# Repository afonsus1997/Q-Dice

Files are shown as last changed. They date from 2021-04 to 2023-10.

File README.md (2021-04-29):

# Q-Dice 

## Quantum dice rolls!!

Open source quantum powered digital dice.



### Resources

* Tm1638 7-seg display driver
  * [Datasheet](https://pdf1.alldatasheet.com/datasheet-pdf/view/1132372/TITAN/TM1638.html)
  * [Diagram](https://www.handsontec.com/dataspecs/display/TM1638.pdf)
  * [mbed](https://os.mbed.com/components/TM1638-LED-controller-80-LEDs-max-Keyboa/)

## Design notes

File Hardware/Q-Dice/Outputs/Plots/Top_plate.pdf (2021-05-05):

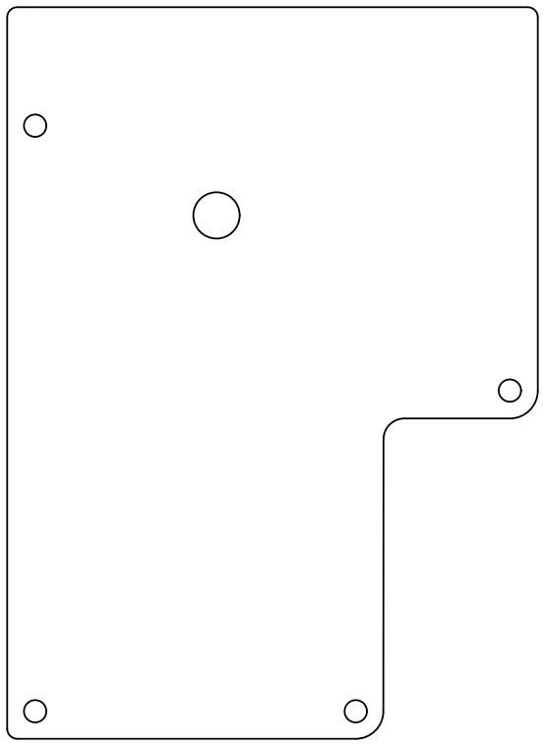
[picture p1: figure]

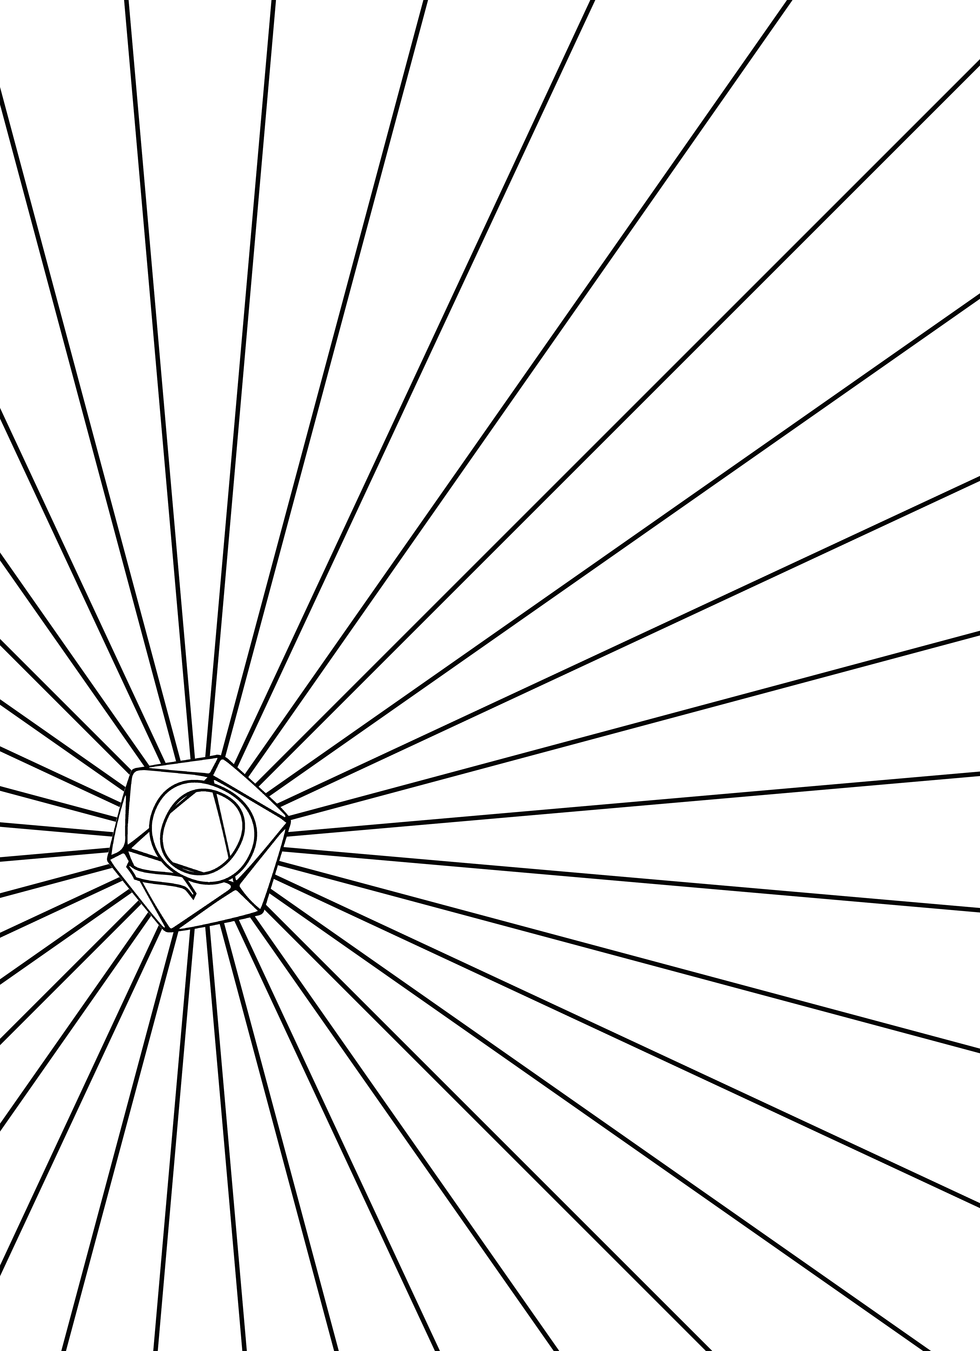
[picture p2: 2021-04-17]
Artwork/back_export.png

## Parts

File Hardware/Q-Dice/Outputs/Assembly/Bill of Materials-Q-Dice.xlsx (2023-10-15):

Designator | Quantity | Comment | Description | Footprint | LibRef
BOOT0 | 1 | 2-Way Solder Jumper |  | SOLDERJUMPER_2WAY_OPEN_NOPASTE | SOLDERJUMPER_2WAY0603
BT1, BT2 | 2 | Holder Cr2032 Gold Leads Smd |  | AAA holder smd | BU2032SM-BT-GTR
CB1, CB2 | 2 | Cap | Capacitor | CAP0603R | Cap
CH1, CH4 | 2 | Cap | Capacitor | C 0603 / 1608 | Cap
CH2, CH3 | 2 | Cap | Capacitor | CAP1206R | Cap
CU2 | 1 | 100nF |  | CAP0603R | Capacitor
DB1 | 1 | SS34 | Default Diode | DO-214AC | Diode
DH1 | 1 | MMSD4148T1G | Switching Diode, 2-Pin SOD-123, Pb-Free, Tape and Reel | ONSC-SOD-123-2-425-04_V | CMP-0895-00001-2
DH2 | 1 | BYG23M | Default Diode | DO-214AC | Diode
DH3 | 1 | LED |  | LED 0603 | LED
DS1 | 1 | 0.36'' |  | 7-seg 3bit 0.36 | BA56-12EWA
DS2 | 1 | 0.56'' |  | BA56-12EWA | BA56-12EWA
JB1, JB2, RB1, RB2, RB3, RB4, RB5, RH1, RH2, RH3, RH4, RH6, RH9, RH10, RH11, RH12, RH13, RH14, RH15, RU1, RU2, RU3, RU4, RU5, RU6, RU7, RU8 | 27 | Res1 | Resistor | RES0603R | Res1
JH1, JH? | 2 | Fuse Clip |  | FUSE_BK-6003 | Fuse Clip
JU1 | 1 | JMP | Resistor | RES0603R | Res1
LB1 | 1 | Inductor | Inductor | INDUCTOR CD54 | Inductor
LH1 | 1 | 12LRS156C | Inductor | IND_12LRS156C | Inductor_Shielded
P1, P2 | 2 | Header 4 | Header, 4-Pin | HDR1X4 | Header 4
P3 | 1 | Header 2 | Header, 2-Pin | HDR1X2 | Header 2
QB1, QH4 | 2 | SSF1341 | P-Channel Power MOSFET PMV65XP | SOT23 | PMOS
QH1 | 1 | STN0214 | NPN Bipolar Transistor | SOT-223-3 - NPN | NPN
QH2, QH3 | 2 | MMBT4401 | General Purpose Transistor, NPN, 0.6 A IC Continuous, 3-Pin SOT23, RoHS, Tape and Reel | ONSC-SOT-23-3-318-08_M | CMP-0722-00001-1
QH5 | 1 | FDN335N | N-Channel Power MOSFET PMV30UN | SOT23 | NMOS
RH5 | 1 | 10R | 3314G-1-502E | 4 mm Square Trimpot(R) Trimming Potentiometer, 5 KOhm, +/- 20%, 0.25 W, -55 to 125 degC, 3-Pin SMD, RoHS, Tape and Reel | BOUR-3314G-1_V | CMP-2000-05589-1
RH7, RH8 | 2 | Res1 | Resistor | RES0805R | Res1
SW1, SW2, SW3 | 3 | EVQ-PAE05R | SWITCH TACTILE SPST-NO 0.02A 15V | FP-EVQ-PAE05R-MFG | CMP-05618-000051-1
SW4 | 1 | FSM100 | SWITCH TACTILE SPST-NO 0.05A 24V | FP-FSM100-MFG | CMP-03402-000014-1
SW5 | 1 | Switch |  | PUSH_SMD_3x4 | B3U-1000P
SW6 | 1 | JS202011SCQN | SWITCH SLIDE DPDT 300MA 6V | JS202011SCQN | JS202011SCQN
TPH1 | 1 | HV_TP |  | TESTPOINT_SMT | TESTPOINT
UB1 | 1 | MT3608 | Boost converter | SOT23-6 | MT3608
UH1 | 1 | NE555P |  | SOIC-8 | NE555P
UU1 | 1 | STM32L053C8T6 | ARMÂ® CortexÂ®-M0+ STM32L0 Microcontroller IC 32-Bit 32MHz 64KB _64K x 8_ FLASH 48-LQFP _7x7_ | LQFP48_7X7MM_0.5MMPP | STM32L053C8T6
UU2 | 1 | TM1638 | 7Seg and keyboard driver | SOP-28 | TM1638

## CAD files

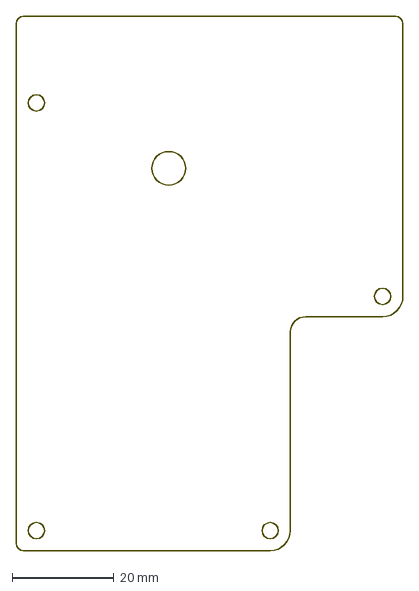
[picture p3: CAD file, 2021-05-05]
Hardware/Q-Dice/Outputs/Plots/Top_plate.DXF
76.0 x 105.0 mm

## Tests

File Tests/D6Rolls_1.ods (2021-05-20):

Dados Históricos
TIME | CH1
20:12:30.17 | 2
20:12:26.92 | 1
20:12:23.32 | 5
20:12:19.59 | 6
20:12:15.48 | 3
20:12:14.38 | 4
20:12:11.02 | 5
20:12:10.89 | 6
20:12:06.22 | 6
20:12:02.99 | 6
20:11:59.48 | 3
20:11:57.77 | 6
20:11:52.44 | 3
20:11:45.64 | 1
20:11:44.19 | 6
20:11:43.87 | 3
20:11:38.67 | 6
20:11:37.69 | 4
20:11:32.68 | 4
20:11:27.77 | 2
20:11:26.56 | 3
20:11:26.06 | 5
20:11:18.01 | 4
20:11:15.53 | 4
20:11:12.72 | 4
20:11:10.36 | 4
20:11:07.93 | 4
20:11:04.40 | 4
20:10:54.44 | 4
20:10:52.16 | 2
20:10:37.60 | 3
20:10:32.62 | 3
20:10:30.83 | 5
20:10:25.04 | 4
20:10:21.13 | 4
20:10:18.06 | 1
20:10:14.40 | 2
20:10:13.16 | 3
20:10:11.71 | 6
20:10:10.48 | 6
20:10:09.77 | 5
20:10:08.70 | 5
20:10:07.18 | 5
20:10:03.79 | 6
20:10:00.17 | 5
20:09:53.13 | 6
20:09:47.84 | 1
20:09:44.59 | 4
20:09:43.48 | 1
20:09:43.24 | 5
20:09:41.52 | 1
20:09:37.60 | 4
20:09:36.84 | 5
20:09:35.47 | 4
20:09:34.03 | 1
20:09:32.96 | 1
20:09:30.52 | 2
20:09:28.56 | 3
20:09:20.28 | 4
20:09:15.12 | 6
20:09:13.90 | 5
20:09:06.78 | 2
20:09:06.08 | 4
20:09:05.79 | 4
20:08:53.60 | 3
20:08:45.52 | 6
20:08:43.31 | 3
20:08:42.56 | 5
20:08:42.22 | 2
20:08:41.39 | 6
20:08:37.82 | 1
20:08:29.98 | 1
20:08:21.90 | 3
20:08:20.24 | 1
20:08:20.03 | 5
20:08:17.72 | 2
20:08:09.20 | 3
20:07:59.18 | 1
20:07:59.15 | 4
20:07:56.27 | 1
20:07:54.97 | 4
20:07:51.13 | 5
20:07:36.30 | 4
20:07:32.67 | 6
20:07:29.82 | 3
20:07:25.63 | 6
20:07:19.77 | 6
20:07:15.55 | 4
20:07:13.95 | 3
20:07:09.04 | 2
20:07:07.64 | 1
20:07:04.86 | 4
20:07:03.23 | 6
20:07:01.36 | 4
20:06:59.61 | 4
20:06:56.04 | 6
20:06:48.28 | 3
20:06:47.53 | 2
20:06:44.36 | 1
20:06:40.96 | 4
20:06:37.31 | 6
20:06:34.43 | 2
20:06:33.53 | 4
20:06:33.39 | 5
20:06:28.71 | 6
20:06:25.48 | 5
20:06:14.27 | 4
20:06:11.60 | 2
20:06:11.56 | 4
20:06:10.48 | 4
20:06:10.46 | 4
20:06:10.06 | 2
20:06:04.59 | 1
20:05:58.17 | 6
20:05:55.76 | 4
20:05:50.25 | 4
20:05:49.72 | 2
20:05:48.57 | 5
20:05:44.54 | 3
20:05:43.93 | 2
20:05:38.19 | 4
20:05:36.22 | 6
20:05:34.65 | 1
20:05:32.75 | 1
20:05:26.06 | 5
20:05:22.92 | 2
20:05:17.45 | 4
20:05:11.58 | 2
20:05:09.47 | 6
20:05:07.74 | 2
20:05:07.63 | 4
20:05:06.01 | 5
20:05:04.44 | 3
20:05:02.00 | 3
20:05:00.11 | 1
20:04:59.34 | 1
20:04:53.77 | 3
20:04:52.36 | 1
20:04:48.11 | 3
20:04:47.45 | 5
20:04:43.13 | 1
20:04:42.43 | 6
20:04:37.90 | 2
20:04:35.00 | 6
20:04:30.70 | 1
20:04:29.18 | 3
20:04:26.59 | 2
20:04:25.45 | 4
20:04:20.67 | 3
20:04:19.60 | 2
20:04:15.36 | 1
20:04:13.58 | 6
20:04:10.28 | 3
20:04:10.17 | 6
20:04:05.53 | 1
20:04:04.92 | 2
20:03:59.95 | 3
20:03:59.37 | 3
20:03:58.97 | 5
20:03:54.60 | 6
20:03:53.16 | 3
20:03:48.08 | 4
20:03:39.23 | 6
20:03:39.04 | 1
20:03:38.48 | 3
20:03:28.51 | 4
20:03:24.32 | 6
20:03:24.30 | 3
20:03:11.72 | 1
20:03:08.76 | 2
20:03:08.36 | 2
20:03:07.34 | 1
20:03:03.68 | 4
20:03:02.59 | 5
20:02:58.46 | 1
20:02:53.77 | 3
20:02:52.80 | 2
20:02:51.48 | 6
20:02:49.98 | 4
20:02:48.16 | 3
20:02:45.13 | 4
20:02:42.03 | 4
20:02:41.60 | 5
20:02:38.80 | 1
20:02:35.04 | 5
20:02:32.97 | 1
20:02:32.12 | 5
20:02:29.40 | 3
20:02:26.14 | 3
20:02:22.99 | 3
20:02:22.54 | 3
20:02:21.80 | 1
20:02:21.07 | 4
20:02:19.85 | 5
20:02:18.65 | 1
20:02:17.87 | 4
20:02:17.58 | 3
20:02:14.14 | 6
20:02:12.03 | 1
20:02:09.40 | 6
20:01:59.88 | 1
20:01:57.53 | 6
20:01:55.32 | 1
20:01:53.55 | 1
20:01:50.84 | 2
20:01:49.21 | 3
20:01:46.72 | 4
20:01:44.67 | 3
20:01:39.61 | 5
20:01:38.75 | 4
20:01:36.16 | 6
20:01:35.24 | 2
20:01:34.65 | 4
20:01:34.52 | 2
20:01:33.45 | 2
20:01:33.08 | 5
20:01:32.73 | 4
20:01:30.51 | 4
20:01:26.54 | 3
20:01:25.63 | 2
20:01:24.32 | 6
20:01:22.44 | 6
20:01:21.98 | 5
20:01:20.75 | 3
20:01:19.53 | 4
20:01:15.84 | 6
20:01:15.18 | 2
20:01:11.32 | 5
20:01:06.67 | 3
20:01:04.64 | 2
20:01:02.28 | 1
20:01:01.28 | 1
20:01:00.28 | 3
20:00:58.67 | 2
20:00:55.12 | 6
20:00:52.65 | 2
20:00:51.69 | 5
20:00:50.11 | 6
20:00:47.98 | 5
20:00:44.46 | 1
20:00:41.31 | 3
20:00:37.34 | 2
20:00:33.98 | 5
20:00:26.43 | 4
20:00:22.49 | 1
20:00:20.40 | 3
20:00:16.46 | 3
20:00:15.47 | 4
20:00:11.98 | 4
20:00:09.00 | 1
20:00:08.65 | 3
20:00:04.88 | 2
20:00:02.96 | 1
20:00:02.46 | 3
19:59:59.58 | 2
19:59:57.13 | 5
19:59:55.29 | 3
19:59:51.95 | 1
19:59:48.92 | 3
19:59:44.27 | 4
19:59:42.86 | 5
19:59:38.62 | 1
19:59:35.92 | 1
19:59:34.41 | 1
19:59:32.55 | 6
19:59:32.52 | 4
19:59:28.28 | 3
19:59:25.88 | 3
19:59:23.56 | 1
19:59:20.97 | 2
19:59:16.14 | 4
19:59:12.03 | 4
19:59:08.06 | 3
19:59:02.73 | 5
19:59:01.80 | 4
19:59:01.69 | 5
19:58:58.27 | 4
19:58:54.99 | 2
19:58:52.88 | 1
19:58:49.13 | 1
19:58:44.62 | 5
19:58:42.65 | 3
19:58:36.81 | 6
19:58:29.52 | 2
19:58:21.87 | 5
19:58:16.91 | 5
19:58:14.72 | 2
19:58:13.55 | 1
19:58:06.24 | 3
19:58:01.08 | 5
19:57:59.40 | 3
19:57:56.81 | 2
19:57:54.44 | 1
19:57:50.33 | 5
19:57:48.76 | 4
19:57:48.30 | 1
19:57:40.20 | 1
19:57:40.03 | 3
19:57:35.74 | 3
19:57:33.74 | 6
19:57:32.63 | 1
19:57:29.37 | 6
19:57:26.51 | 6
19:57:24.99 | 6
19:57:21.68 | 2
19:57:15.98 | 3
19:57:14.80 | 3
19:57:14.38 | 2
19:57:12.59 | 4
19:57:05.72 | 6
19:57:05.60 | 1
19:57:04.51 | 2
19:57:00.83 | 3
19:56:58.41 | 4
19:56:56.03 | 4
19:56:54.52 | 2
19:56:54.32 | 5
19:56:49.40 | 3
19:56:46.14 | 1
19:56:44.03 | 6
19:56:39.90 | 5
19:56:37.92 | 4
19:56:34.76 | 2
19:56:29.76 | 3
19:56:25.61 | 2
19:56:23.53 | 6
19:56:20.46 | 1
19:56:15.19 | 2
19:56:08.48 | 1
19:56:05.61 | 1
19:56:04.46 | 3
19:55:57.76 | 4
19:55:53.52 | 3
19:55:52.35 | 5
19:55:47.15 | 4
19:55:41.34 | 5
19:55:40.78 | 1
19:55:36.99 | 1
19:55:35.58 | 6
19:55:24.11 | 2
19:55:21.18 | 3
19:55:08.27 | 4
19:55:03.90 | 4
19:55:00.14 | 5
19:54:53.10 | 5
19:54:49.61 | 4
19:54:47.69 | 5
19:54:44.64 | 5
19:54:41.29 | 6
19:54:41.00 | 1
19:54:38.91 | 3
19:54:35.74 | 5
19:54:31.40 | 4
19:54:28.09 | 2
19:54:25.50 | 3
19:54:24.48 | 3
19:54:20.89 | 5
19:54:18.70 | 6
19:54:17.48 | 5
19:54:09.56 | 4
19:54:09.36 | 3
19:54:08.83 | 5
19:54:05.61 | 2
19:54:02.46 | 2
19:54:00.17 | 3
19:53:59.76 | 5
19:53:59.61 | 3
19:53:59.12 | 1
19:53:58.83 | 3
19:53:52.41 | 2
19:53:51.80 | 6
19:53:50.78 | 3
19:53:47.04 | 5
19:53:43.59 | 3
19:53:43.52 | 6
19:53:35.88 | 1
19:53:34.57 | 6
19:53:33.08 | 1
19:53:32.89 | 4
19:53:28.44 | 1
19:53:26.00 | 2
19:53:18.94 | 4
19:53:16.40 | 6
19:53:09.56 | 6
19:53:08.72 | 6
19:53:06.65 | 1
19:52:59.13 | 6
19:52:58.28 | 4
19:52:54.68 | 3
19:52:51.26 | 2
19:52:44.19 | 1
19:52:40.89 | 5
19:52:36.28 | 3
19:52:32.19 | 3
19:52:30.28 | 1
19:52:29.39 | 1
19:52:26.99 | 2
19:52:24.60 | 1
19:52:21.79 | 3
19:52:19.10 | 2
19:52:17.48 | 2
19:52:13.15 | 3
19:52:11.69 | 2
19:52:11.55 | 1
19:52:09.79 | 4
19:52:09.77 | 6
19:52:06.22 | 6
19:51:57.23 | 6
19:51:55.18 | 6
19:51:49.53 | 5
19:51:47.63 | 6
19:51:46.86 | 3
19:51:45.55 | 1
19:51:45.50 | 1
19:51:43.34 | 5
19:51:41.05 | 1
19:51:36.94 | 1
19:51:36.48 | 2
19:51:35.00 | 1
19:51:28.68 | 6
19:51:25.10 | 4
19:51:22.67 | 2
19:51:19.79 | 3
19:51:06.65 | 1
19:51:04.68 | 2
19:51:02.33 | 3
19:51:00.84 | 6
19:50:56.86 | 3
19:50:56.67 | 2
19:50:53.13 | 2
19:50:48.62 | 6
19:50:47.50 | 4
19:50:42.75 | 1
19:50:42.44 | 1
19:50:34.22 | 3
19:50:32.28 | 4
19:50:31.28 | 4
19:50:27.77 | 3
19:50:25.43 | 1
19:50:20.67 | 5
19:50:17.87 | 1
19:50:14.88 | 6
19:50:12.99 | 3
19:50:09.80 | 6
19:50:05.58 | 3
19:50:03.66 | 6
19:50:01.92 | 3
19:49:58.75 | 6
19:49:55.64 | 3
19:49:50.54 | 6
19:49:46.75 | 2
19:49:46.33 | 5
19:49:46.08 | 6
19:49:44.24 | 2
19:49:38.43 | 3
19:49:37.16 | 4
19:49:35.66 | 6
19:49:34.30 | 6
19:49:28.01 | 6
19:49:23.39 | 4
19:49:19.48 | 1
19:49:16.91 | 1
19:49:16.89 | 1
19:49:16.44 | 1
19:49:14.06 | 2
19:49:13.88 | 3
19:49:09.40 | 5
19:49:07.98 | 5
19:49:01.61 | 4
19:49:00.57 | 2
19:48:57.96 | 3
19:48:55.28 | 3
19:48:54.51 | 6
19:48:52.73 | 3
19:48:48.72 | 2
19:48:46.73 | 1
19:48:43.66 | 5
19:48:42.25 | 2
19:48:37.24 | 3
19:48:35.95 | 3
19:48:35.66 | 1
19:48:34.20 | 5
19:48:29.55 | 6
19:48:26.73 | 5
19:48:19.29 | 3
19:48:15.10 | 4
19:48:14.36 | 3
19:48:11.28 | 2
19:48:10.00 | 3
19:48:04.84 | 2
19:48:03.24 | 1
19:47:58.20 | 2
19:47:54.33 | 5
19:47:46.73 | 2
19:47:42.96 | 6
19:47:38.39 | 1
19:47:36.84 | 6
19:47:35.74 | 3
19:47:34.16 | 6
19:47:31.84 | 4
19:47:17.66 | 6
19:47:07.95 | 4
19:47:06.14 | 4
19:46:57.53 | 1
19:46:56.88 | 2
19:46:49.42 | 1
19:46:47.24 | 3
19:46:45.66 | 6
19:46:37.52 | 2
19:46:22.36 | 4
19:46:20.12 | 4
19:46:08.64 | 5
19:46:05.80 | 6
19:46:02.88 | 1
19:45:57.07 | 2
19:45:56.20 | 6
19:45:55.68 | 3
19:45:53.52 | 6
19:45:48.49 | 3
19:45:42.40 | 1
19:45:38.11 | 4
19:45:34.43 | 6
19:45:31.53 | 5
19:45:26.51 | 3
19:45:19.77 | 6
19:45:17.27 | 3
19:45:17.12 | 2
19:45:15.23 | 1
19:45:14.48 | 2
19:45:10.88 | 6
19:45:07.32 | 3
19:45:04.83 | 3
19:45:02.89 | 1
19:45:01.05 | 5
19:44:58.30 | 1
19:44:56.44 | 4
19:44:55.23 | 3
19:44:52.00 | 3
19:44:50.78 | 6
19:44:43.95 | 4
19:44:41.92 | 5
19:44:38.71 | 4
19:44:37.59 | 4
19:44:37.18 | 5
19:44:30.76 | 4
19:44:30.27 | 1
19:44:28.56 | 1
19:44:26.40 | 1
19:44:24.17 | 1
19:44:21.80 | 4
19:44:13.42 | 2
19:44:09.04 | 6
19:44:08.24 | 5
19:44:05.13 | 5
19:44:00.38 | 4
19:43:58.88 | 6
19:43:53.40 | 3
19:43:52.65 | 6
19:43:45.88 | 4
19:43:45.15 | 5
19:43:39.50 | 6
19:43:36.80 | 6
19:43:33.79 | 1
19:43:27.72 | 6
19:43:25.92 | 3
19:43:22.17 | 3
19:43:21.69 | 1
19:43:21.44 | 3
19:43:19.68 | 4
19:43:18.33 | 1
19:43:13.26 | 2
19:43:11.53 | 5
19:43:04.48 | 5
19:43:03.58 | 5
19:43:01.69 | 3
19:42:59.95 | 3
19:42:59.52 | 4
19:42:52.48 | 5
19:42:50.03 | 3
19:42:48.60 | 4
19:42:46.75 | 4
19:42:46.12 | 6
19:42:43.07 | 6
19:42:42.36 | 1
19:42:39.08 | 3
19:42:38.68 | 1
19:42:31.68 | 5
19:42:27.18 | 1
19:42:26.46 | 1
19:42:25.05 | 5
19:42:23.37 | 4
19:42:17.98 | 4
19:42:15.34 | 4
19:42:14.11 | 1
19:42:13.69 | 3
19:42:05.15 | 3
19:42:02.30 | 1
19:41:57.02 | 1
19:41:55.36 | 4
19:41:51.72 | 3
19:41:49.88 | 2
19:41:37.68 | 4
19:41:37.34 | 5
19:41:35.71 | 5
19:41:29.31 | 2
19:41:26.99 | 1
19:41:23.63 | 2
19:41:20.70 | 6
19:41:19.28 | 3
19:41:09.31 | 5
19:40:57.71 | 1
19:40:53.74 | 3
19:40:50.91 | 2
19:40:47.08 | 6
19:40:44.56 | 1
19:40:41.52 | 2
19:40:37.24 | 3
19:40:33.26 | 4
19:40:32.30 | 1
19:40:29.08 | 4
19:40:25.61 | 6
19:40:21.44 | 1
19:40:16.60 | 4
19:40:10.27 | 1
19:40:07.28 | 3
19:40:05.95 | 3
19:40:04.86 | 2
19:40:04.27 | 3
19:40:03.77 | 5
19:40:01.72 | 4
19:39:59.60 | 6
19:39:55.05 | 4
19:39:49.74 | 1
19:39:37.77 | 1
19:39:37.52 | 3
19:39:31.84 | 1
19:39:28.84 | 3
19:39:27.93 | 3
19:39:25.61 | 1
19:39:25.00 | 6
19:39:21.19 | 6
19:39:18.25 | 3
19:39:14.49 | 2
19:39:14.25 | 6
19:39:08.59 | 5
19:39:07.34 | 3
19:39:05.18 | 4
19:38:59.34 | 3
19:38:58.41 | 4
19:38:52.78 | 4
19:38:47.83 | 6
19:38:45.93 | 1
19:38:45.02 | 6
19:38:42.08 | 6
19:38:42.00 | 5
19:38:36.33 | 4
19:38:33.55 | 2
19:38:28.86 | 5
19:38:28.60 | 4
19:38:26.41 | 5
19:38:23.63 | 6
19:38:22.60 | 1
19:38:20.19 | 3
19:38:19.12 | 5
19:38:16.24 | 1
19:38:13.29 | 2
19:38:12.78 | 4
19:38:08.97 | 1
19:38:05.87 | 2
19:38:04.51 | 4
19:37:58.59 | 5
19:37:56.89 | 3
19:37:51.47 | 2
19:37:48.49 | 3
19:37:42.46 | 4
19:37:42.12 | 4
19:37:39.23 | 1
19:37:35.05 | 1
19:37:33.16 | 5
19:37:20.36 | 3
19:37:16.51 | 2
19:37:13.32 | 3
19:37:10.24 | 2
19:37:07.12 | 6
19:37:04.16 | 3
19:36:59.18 | 1
19:36:53.43 | 6
19:36:49.31 | 4
19:36:45.58 | 4
19:36:42.17 | 5
19:36:41.53 | 2
19:36:39.10 | 6
19:36:37.55 | 1
19:36:37.47 | 2
19:36:36.51 | 3
19:36:36.03 | 1
19:36:28.44 | 1
19:36:24.83 | 1
19:36:23.29 | 1
19:36:17.18 | 2
19:36:16.22 | 1
19:36:05.34 | 4
19:36:02.36 | 1
19:36:00.33 | 1
19:35:47.66 | 2
19:35:46.78 | 4
19:35:45.32 | 2
19:35:39.18 | 5
19:35:32.35 | 4
19:35:32.28 | 5
19:35:23.03 | 6
19:35:21.56 | 4
19:35:17.32 | 6
19:35:05.66 | 1
19:35:04.76 | 3
19:35:03.58 | 4
19:35:03.26 | 1
19:35:02.76 | 5
19:34:58.91 | 3
19:34:55.85 | 2
19:34:51.66 | 4
19:34:50.23 | 4
19:34:43.88 | 2
19:34:42.08 | 3
19:34:37.60 | 3
19:34:34.48 | 1
19:34:29.72 | 1
19:34:24.99 | 1
19:34:24.81 | 2
19:34:20.38 | 4
19:34:16.11 | 3
19:34:14.48 | 2
19:34:09.48 | 5
19:34:07.26 | 3
19:34:05.87 | 6
19:34:01.95 | 3
19:34:00.12 | 1
19:33:56.08 | 3
19:33:50.86 | 3
19:33:44.54 | 6
19:33:43.45 | 5
19:33:38.73 | 1
19:33:36.24 | 6
19:33:29.92 | 5
19:33:20.97 | 3
19:33:18.70 | 3
19:33:14.09 | 2
19:33:12.03 | 1
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

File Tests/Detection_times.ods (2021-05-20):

TIME | CH1
17:47:18.66 | 1
17:47:05.98 | 1
17:47:03.02 | 1
17:46:53.39 | 1
17:46:43.18 | 1
17:46:41.60 | 1
17:46:39.92 | 1
17:46:34.48 | 1
17:46:29.64 | 1
17:46:25.13 | 1
17:46:13.58 | 1
17:45:54.54 | 1
17:45:47.88 | 1
17:45:18.16 | 1
17:45:12.52 | 1
17:45:06.30 | 1
17:45:01.07 | 1
17:44:51.56 | 1
17:44:42.57 | 1
17:44:36.46 | 1
17:44:13.87 | 1
17:44:09.11 | 1
17:44:08.22 | 1
17:43:58.97 | 1
17:43:51.56 | 1
17:43:41.66 | 1
17:43:07.91 | 1
17:42:51.45 | 1
17:42:47.72 | 1
17:42:43.52 | 1
17:42:38.67 | 1
17:42:23.37 | 1
17:42:18.41 | 1
17:42:12.67 | 1
17:42:04.20 | 1
17:41:39.07 | 1
17:41:36.76 | 1
17:41:27.90 | 1
17:41:24.27 | 1
17:41:02.79 | 1
17:40:37.15 | 1
17:40:27.00 | 1
17:40:21.19 | 1
17:40:14.30 | 1
17:40:05.58 | 1
17:40:02.51 | 1
17:39:54.99 | 1
17:39:52.22 | 1
17:39:43.43 | 1
17:39:41.79 | 1
17:39:38.87 | 1
17:39:27.58 | 1
17:39:13.80 | 1
17:39:07.93 | 1
17:39:07.21 | 1
17:39:05.47 | 1
17:39:00.23 | 1
17:38:54.63 | 1
17:38:15.72 | 1
17:38:08.35 | 1
17:38:04.70 | 1
17:37:59.69 | 1
17:37:53.59 | 1
17:37:49.40 | 1
17:37:31.98 | 1
17:37:19.35 | 1
17:37:15.26 | 1
17:37:13.45 | 1
17:37:10.92 | 1
17:37:09.11 | 1
17:37:05.07 | 1
17:37:04.97 | 1
17:36:56.01 | 1
17:36:52.89 | 1
17:36:45.90 | 1
17:36:41.87 | 1
17:36:37.37 | 1
17:36:21.95 | 1
17:36:04.95 | 1
17:36:04.59 | 1
17:35:54.17 | 1
17:35:52.43 | 1
17:35:49.02 | 1
17:35:24.43 | 1
17:35:22.30 | 1
17:35:19.05 | 1
17:35:15.75 | 1
17:35:10.25 | 1
17:34:57.67 | 1
17:34:53.02 | 1
17:34:43.32 | 1
17:34:40.25 | 1
17:34:31.39 | 1
17:34:24.57 | 1
17:34:23.31 | 1
17:34:18.03 | 1
17:34:16.39 | 1
17:34:12.11 | 1
17:34:07.45 | 1
17:34:07.16 | 1
17:33:55.87 | 1
17:33:52.57 | 1
17:33:45.34 | 1
17:33:44.25 | 1
17:33:41.05 | 1
17:33:37.90 | 1
17:33:31.69 | 1
17:33:17.51 | 1
17:33:12.17 | 1
17:33:11.21 | 1
17:33:02.39 | 1
17:32:56.20 | 1
17:32:54.62 | 1
17:32:46.71 | 1
17:32:43.39 | 1
17:32:35.69 | 1
17:32:25.27 | 1
17:32:18.34 | 1
17:32:10.06 | 1
17:32:08.86 | 1
17:31:55.24 | 1
17:31:51.98 | 1
17:31:48.04 | 1
17:31:46.44 | 1
17:31:45.80 | 1
17:31:42.06 | 1
17:31:40.39 | 1
17:31:35.51 | 1
17:31:31.40 | 1
17:31:28.83 | 1
17:31:21.69 | 1
17:31:14.17 | 1
17:31:10.97 | 1
17:31:07.22 | 1
17:31:04.61 | 1
17:31:03.64 | 1
17:30:59.48 | 1
17:30:58.20 | 1
17:30:47.99 | 1
17:30:46.31 | 1
17:30:46.12 | 1
17:30:39.89 | 1
17:30:35.14 | 1
17:30:33.76 | 1
17:30:18.81 | 1
17:30:09.64 | 1
17:30:08.65 | 1
17:30:05.03 | 1
17:30:00.89 | 1
17:29:59.64 | 1
17:29:56.12 | 1
17:29:36.39 | 1
17:29:31.77 | 1
17:29:29.00 | 1
17:29:22.49 | 1
17:29:18.21 | 1
17:29:15.05 | 1
17:29:13.00 | 1
17:29:11.35 | 1
17:29:04.79 | 1
17:28:55.88 | 1
17:28:55.41 | 1
17:28:48.44 | 1
17:28:44.66 | 1
17:28:13.24 | 1
17:28:08.05 | 1
17:28:02.39 | 1
17:27:55.25 | 1
17:27:47.38 | 1
17:27:47.06 | 1
17:27:38.42 | 1
17:27:30.74 | 1
17:27:23.17 | 1
17:27:21.73 | 1
17:27:02.55 | 1
17:27:00.00 | 1
17:26:55.94 | 1
17:26:53.30 | 1
17:26:48.37 | 1
17:26:38.57 | 1
17:26:36.31 | 1
17:26:26.55 | 1
17:26:23.88 | 1
17:26:14.90 | 1
17:26:09.64 | 1
17:26:07.56 | 1
17:26:03.97 | 1
17:26:03.24 | 1
17:26:01.22 | 1
17:25:48.05 | 1
17:25:44.34 | 1
17:25:37.49 | 1
17:25:30.41 | 1
17:25:25.17 | 1
17:25:24.15 | 1
17:25:19.83 | 1
17:25:18.63 | 1
17:25:18.16 | 1
17:25:15.81 | 1
17:25:09.73 | 1
17:25:02.02 | 1
17:24:56.42 | 1
17:24:54.44 | 1
17:24:43.80 | 1
17:24:34.04 | 1
17:24:30.80 | 1
17:24:25.04 | 1
17:24:22.41 | 1
17:24:18.20 | 1
17:24:03.54 | 1
17:24:03.17 | 1
17:24:00.53 | 1
17:23:49.19 | 1
17:23:46.18 | 1
17:23:38.88 | 1
17:23:34.37 | 1
17:23:22.95 | 1
17:23:06.12 | 1
17:23:03.80 | 1
17:22:59.60 | 1
17:22:58.74 | 1
17:22:53.43 | 1
17:22:51.94 | 1
17:22:51.83 | 1
17:22:42.90 | 1
17:22:36.74 | 1
17:22:29.32 | 1
17:22:28.09 | 1
17:22:19.94 | 1
17:22:18.44 | 1
17:21:39.46 | 1
17:21:36.63 | 1
17:21:24.98 | 1
17:21:22.76 | 1
17:21:20.96 | 1
17:21:18.55 | 1
17:21:17.62 | 1
17:21:15.57 | 1
17:21:13.92 | 1
17:21:04.31 | 1
17:21:01.17 | 1
17:21:00.40 | 1
17:20:58.21 | 1
17:20:57.60 | 1
17:20:56.48 | 1
17:20:55.09 | 1
17:20:51.52 | 1
17:20:49.96 | 1
17:20:49.19 | 1
17:20:47.60 | 1
17:20:43.00 | 1
17:20:42.68 | 1
17:20:41.92 | 1
17:20:41.83 | 1
17:20:40.48 | 1
17:20:39.91 | 1
17:20:39.59 | 1
17:20:36.40 | 1
17:20:36.34 | 1
17:20:35.65 | 1
17:20:34.52 | 1
17:20:32.77 | 1
17:20:31.49 | 1
17:20:24.98 | 1
17:20:23.92 | 1
17:20:22.92 | 1
17:20:20.90 | 1
17:20:18.66 | 1
17:20:17.56 | 1
17:20:16.32 | 1
17:20:15.70 | 1
17:20:14.16 | 1
17:20:12.12 | 1
17:20:12.08 | 1
17:20:06.20 | 1
17:20:05.64 | 1
17:20:04.88 | 1
17:20:03.92 | 1
17:20:01.40 | 1
17:19:58.82 | 1
17:19:57.99 | 1
17:19:56.12 | 1
17:19:55.73 | 1
17:19:54.91 | 1
17:19:53.83 | 1
17:19:51.56 | 1
17:19:49.30 | 1
17:19:48.82 | 1
17:19:47.68 | 1
17:19:47.01 | 1
17:19:44.68 | 1
17:19:42.77 | 1
17:19:42.07 | 1
17:19:40.10 | 1
17:19:37.99 | 1
17:19:37.17 | 1
17:19:36.04 | 1
17:19:33.65 | 1
17:19:32.72 | 1
17:19:30.07 | 1
17:19:28.61 | 1
17:19:27.97 | 1
17:19:25.62 | 1
17:19:24.52 | 1
17:19:17.11 | 1
17:19:15.44 | 1
17:19:13.83 | 1
17:19:13.62 | 1
17:19:11.33 | 1
17:19:08.53 | 1
17:19:06.40 | 1
17:19:05.67 | 1
17:19:04.93 | 1
17:19:04.50 | 1
17:18:58.88 | 1
17:18:58.69 | 1
17:18:56.85 | 1
17:18:56.71 | 1
17:18:53.72 | 1
17:18:53.59 | 1
17:18:52.26 | 1
17:18:51.99 | 1
17:18:49.36 | 1
17:18:48.44 | 1
17:18:47.75 | 1
17:18:46.60 | 1
17:18:45.72 | 1
17:18:44.40 | 1
17:18:43.06 | 1
17:18:40.60 | 1
17:18:39.57 | 1
17:18:39.12 | 1
17:18:39.06 | 1
17:18:33.94 | 1
17:18:32.34 | 1
17:18:32.00 | 1
17:18:27.03 | 1
17:18:26.56 | 1
17:18:25.83 | 1
17:18:24.69 | 1
17:18:23.03 | 1
17:18:20.76 | 1
17:18:20.50 | 1
17:18:19.49 | 1
17:18:17.49 | 1
17:18:16.74 | 1
17:18:15.78 | 1
17:18:14.20 | 1
17:18:14.13 | 1
17:18:12.82 | 1
17:18:12.45 | 1
17:18:11.22 | 1
17:18:09.43 | 1
17:18:09.27 | 1
17:18:07.00 | 1
17:18:05.32 | 1
17:18:04.55 | 1
17:18:04.00 | 1
17:18:01.48 | 1
17:18:01.04 | 1
17:17:59.84 | 1
17:17:59.04 | 1
17:17:57.65 | 1
17:17:56.53 | 1
17:17:53.88 | 1
17:17:53.25 | 1
17:17:51.71 | 1
17:17:51.49 | 1
17:17:50.13 | 1
17:17:50.08 | 1
17:17:49.00 | 1
17:17:47.92 | 1
17:17:46.53 | 1
17:17:45.17 | 1
17:17:43.12 | 1
17:17:41.40 | 1
17:17:37.04 | 1
17:17:36.08 | 1
17:17:35.88 | 1
17:17:34.31 | 1
17:17:30.40 | 1
17:17:28.24 | 1
17:17:24.87 | 1
17:17:24.21 | 1
17:17:23.51 | 1
17:17:22.13 | 1
17:17:21.22 | 1
17:17:15.83 | 1
17:17:15.73 | 1
17:17:07.76 | 1
17:17:07.44 | 1
17:17:07.24 | 1
17:17:07.14 | 1
17:17:06.61 | 1
17:17:03.64 | 1
17:17:02.96 | 1
17:17:00.18 | 1
17:16:58.90 | 1
17:16:58.61 | 1
17:16:57.43 | 1
17:16:54.55 | 1
17:16:52.32 | 1
17:16:51.09 | 1
17:16:48.92 | 1
17:16:47.80 | 1
17:16:46.96 | 1
17:16:43.54 | 1
17:16:42.79 | 1
17:16:42.23 | 1
17:16:40.24 | 1
17:16:38.20 | 1
17:16:37.78 | 1
17:16:36.23 | 1
17:16:34.10 | 1
17:16:32.24 | 1
17:16:31.78 | 1
17:16:27.72 | 1
17:16:26.90 | 1
17:16:15.03 | 1
17:16:11.06 | 1
17:16:10.72 | 1
17:16:02.82 | 1
17:16:00.98 | 1
17:15:56.50 | 1
17:15:53.62 | 1
17:15:48.42 | 1
17:15:45.47 | 1
17:15:37.81 | 1
17:15:34.19 | 1
17:15:33.76 | 1
17:15:29.76 | 1
17:15:28.56 | 1

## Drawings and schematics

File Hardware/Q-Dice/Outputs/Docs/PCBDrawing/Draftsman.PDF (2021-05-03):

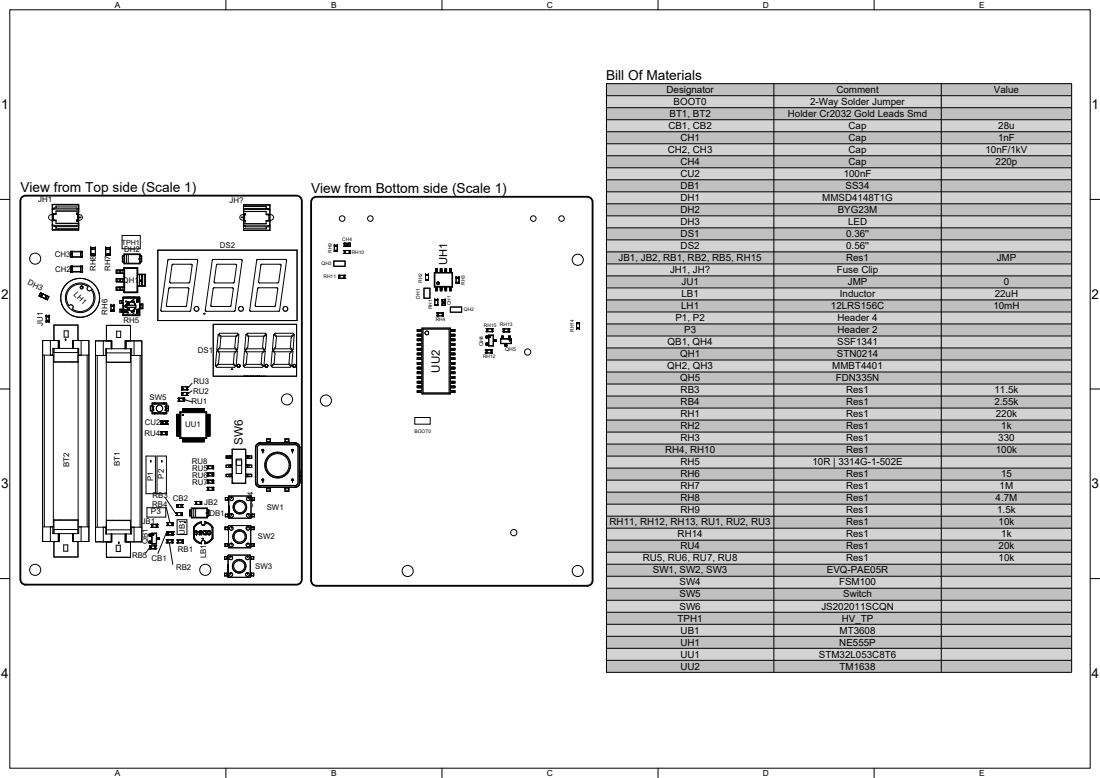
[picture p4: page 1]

Comment
2-Way Solder Jumper
Holder Cr2032 Gold Leads Smd

View from Top side (Scale 1)

View from Bottom side (Scale 1)

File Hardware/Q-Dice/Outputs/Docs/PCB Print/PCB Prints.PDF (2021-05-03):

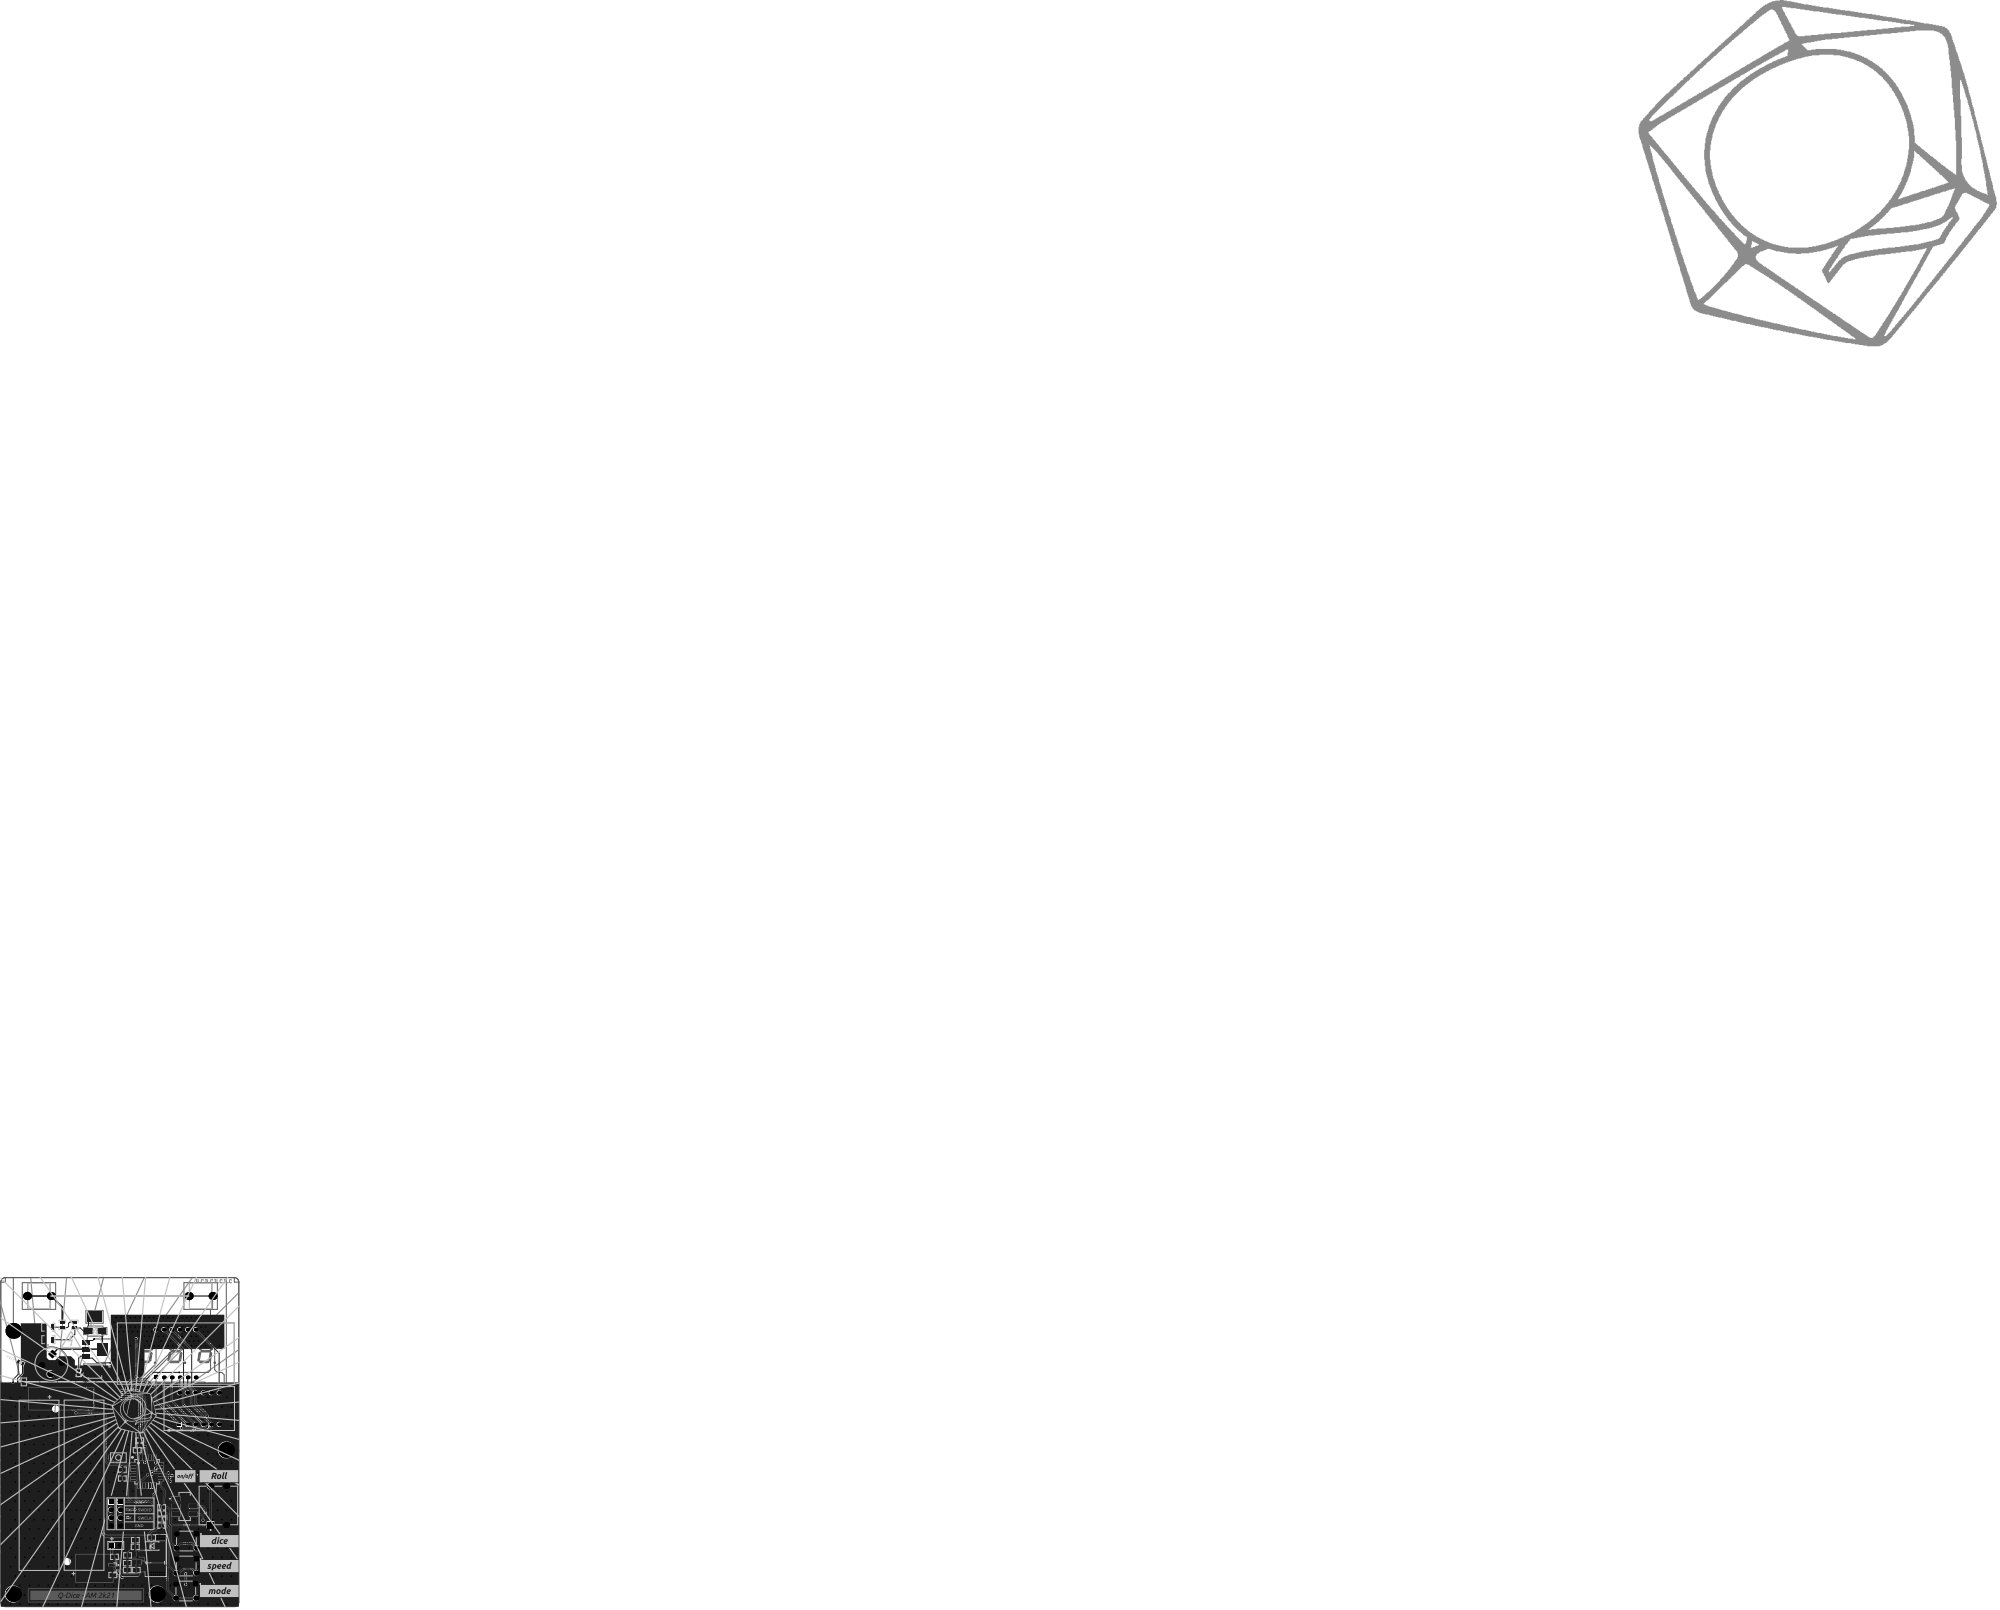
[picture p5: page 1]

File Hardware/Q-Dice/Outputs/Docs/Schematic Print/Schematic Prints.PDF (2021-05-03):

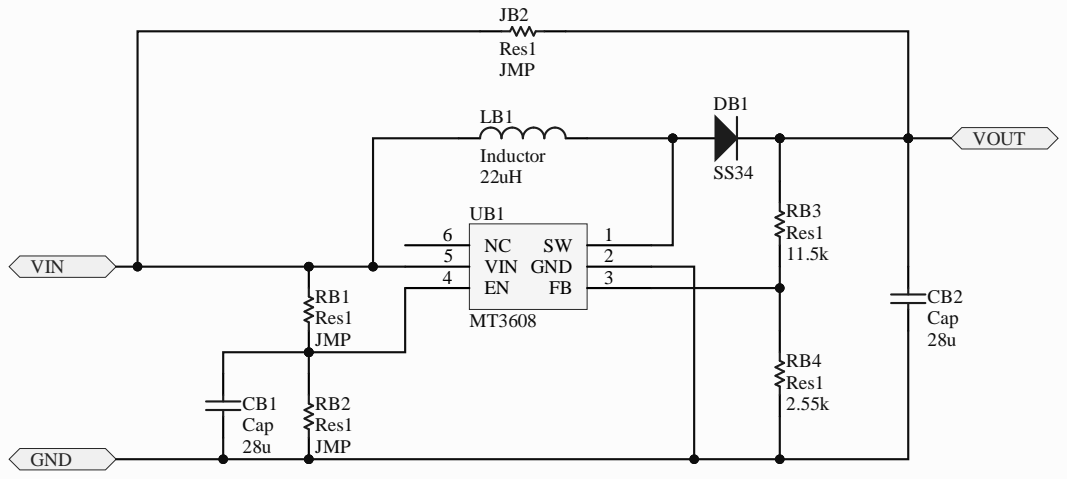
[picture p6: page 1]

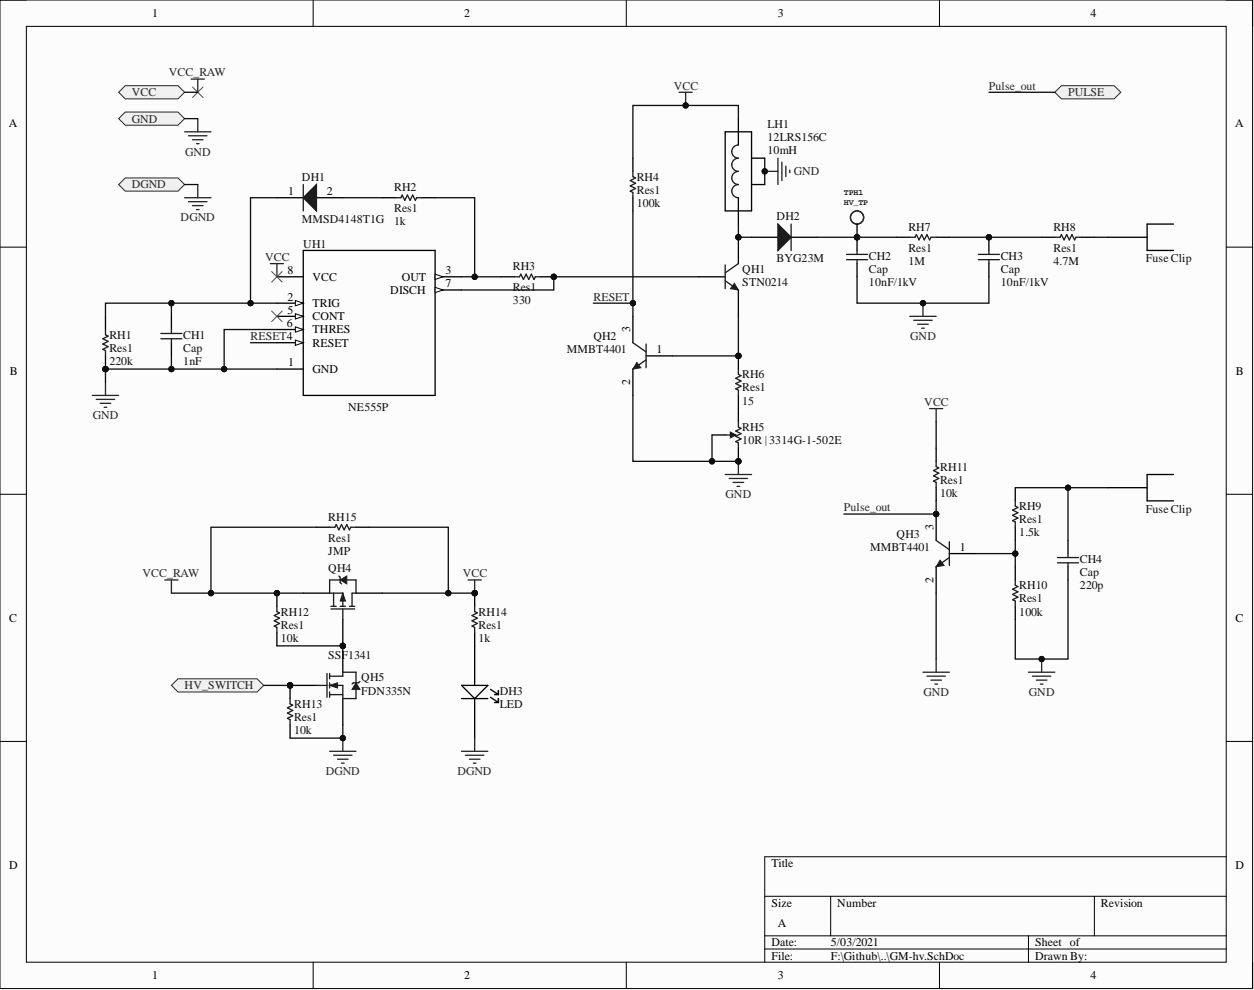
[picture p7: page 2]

RESET 4 THRES 6 CONT 5 TRIG 2

RESET

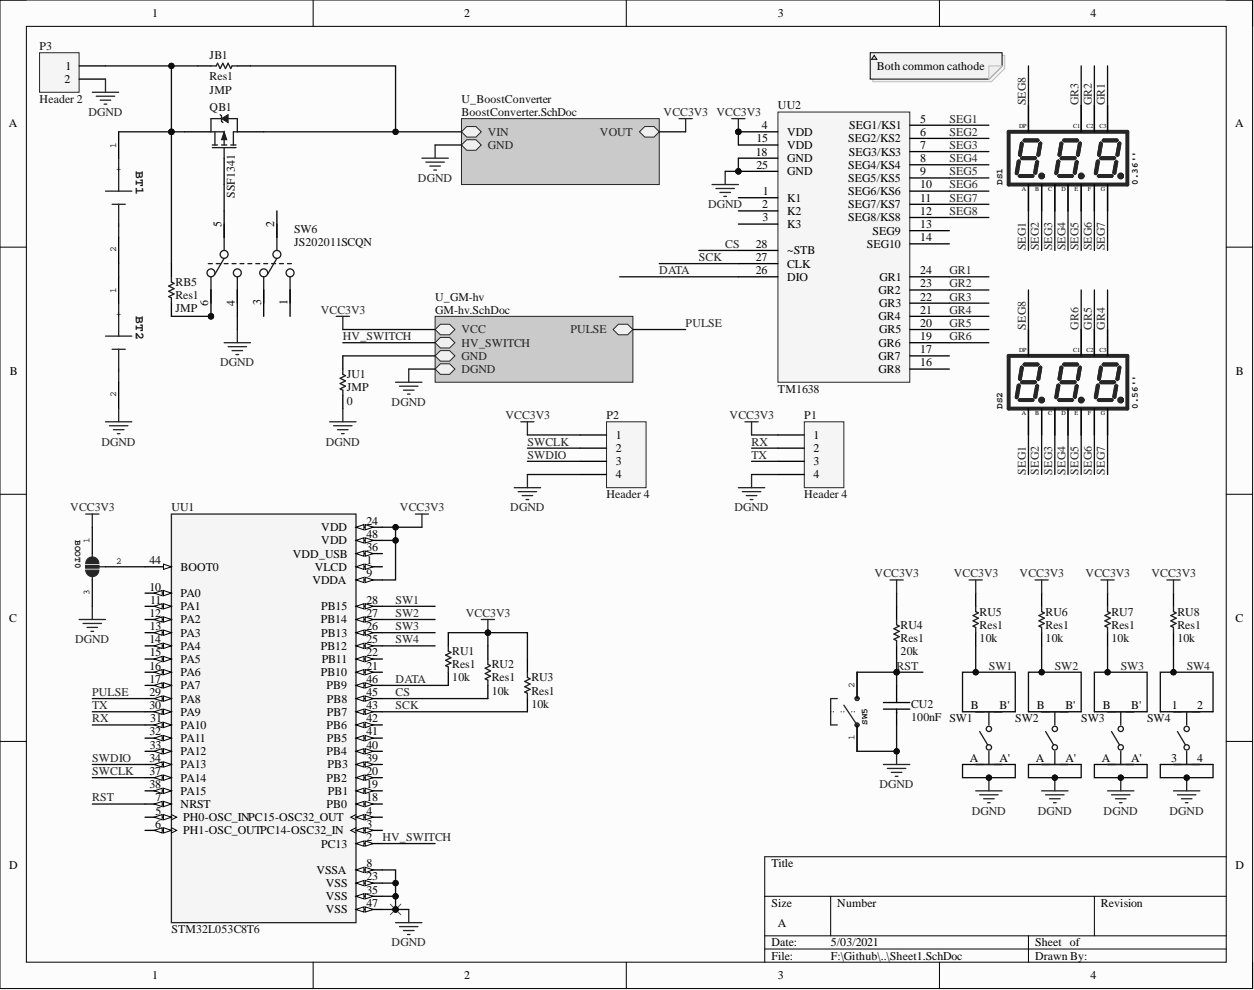
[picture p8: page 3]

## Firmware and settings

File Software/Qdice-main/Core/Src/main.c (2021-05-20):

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
/* Includes ------------------------------------------------------------------*/
#include "main.h"

/* USER CODE BEGIN Includes */
#include <stdbool.h>
#include <string.h>
#include "retarget.h"
#include "tm1638lib.h" //include the library
#include "tm1638fonts.h"
/* USER CODE END Includes */

/* USER CODE BEGIN PM */
#define NDICES 7
#define DEBOUNCE_TIME_MS 200

//#define DEBUG_1
//#define DEBUG_3

/* USER CODE END PM */

UART_HandleTypeDef huart1;

/* USER CODE BEGIN PV */

enum Dices_e{
		D2,
		D4,
		D6,
		D8,
		D10,
		D12,
		D20
};

enum Switches_e{
		Roll,
		Dice,
		Speed,
		Mode
};

volatile uint32_t currentTick, currentDetectTick, lastDetectTick;
uint8_t dices[NDICES] = {2, 4, 6, 8, 10, 12, 20};
uint8_t currentDice = 0;
bool rolling = 0;
uint8_t rollNumber = 0;
uint32_t lastPress = 0;
uint8_t lastSwStates[4] = {0, 0, 0, 0};
uint8_t currentSwStates[4] = {0, 0, 0, 0};


uint8_t MSG[35];
uint8_t MSG2[35];
uint8_t dispHigh[3];
uint8_t dispLow[3];


/* USER CODE END PV */

void SystemClock_Config(void);
static void MX_GPIO_Init(void);
static void MX_USART1_UART_Init(void);
/* USER CODE BEGIN 0 */


void readSW(){
	currentSwStates[Roll] = HAL_GPIO_ReadPin(SW_ROLL_GPIO_Port, SW_ROLL_Pin);
	currentSwStates[Dice] = HAL_GPIO_ReadPin(SW_DICE_GPIO_Port, SW_DICE_Pin);
	currentSwStates[Speed] = HAL_GPIO_ReadPin(SW_SPEED_GPIO_Port, SW_SPEED_Pin);
	currentSwStates[Mode] = HAL_GPIO_ReadPin(SW_MODE_GPIO_Port, SW_MODE_Pin);

}

uint8_t debounceCheck(uint8_t readState, uint8_t diceCode){
	if(lastSwStates[diceCode] == readState)
		return 0;
	else{
		lastSwStates[diceCode] = readState;
		return 1;
	}
}

//int _write(int32_t file, uint8_t *ptr, int32_t len)
//{
//	for (int i = 0; i < len; i++)
//	{
//		ITM_SendChar(*ptr++);
//	}
//	return len;
//}

uint32_t reverse(uint32_t x)
{
	uint32_t rem, sum = 0;
    while(x > 0)
    {
        rem = x%10;
        sum = (sum*10) + rem;
        x = x/10;
    }
    return sum;
}

void HAL_GPIO_EXTI_Callback(uint16_t GPIO_Pin){
	if(GPIO_Pin == INT_PULSE_Pin){
#ifdef DEBUG_2
		printf("1,\r\n", rollNumber);
#endif
		currentDetectTick = HAL_GetTick();
#ifndef DEBUG_3
		if(rolling){
#endif
			rolling = false;
//			if(currentDetectTick == lastDetectTick)
//				return;
			lastDetectTick = currentDetectTick;
			currentDetectTick = (HAL_GetTick() * currentDetectTick) % 100;
//			currentDetectTick =  * lastDetectTick;
//			lastDetectTick = currentDetectTick;
//			currentDetectTick = (currentDetectTick * lastDetectTick) % 100;
			rollNumber = (currentDetectTick % dices[currentDice]) + 1;

//			rollNumber = (r % dices[currentDice]) + 1;
			sprintf(dispHigh, "%03d", rollNumber);
			setDisplayToString(dispHigh, 0, 3, FONT_DEFAULT);
#ifdef DEBUG_3
			printf("%d,\r\n", rollNumber);
#endif
#ifdef DEBUG_1
			printf("Rolled dice: %d\r\n", rollNumber);
#endif
//			HAL_GPIO_WritePin(SW_HV_GPIO_Port, SW_HV_Pin, RESET);
#ifndef DEBUG_3
		}
#endif
	}
}

/* USER CODE END 0 */

/**
  * @brief  The application entry point.
  * @retval int
  */
int main(void)
{
  /* MCU Configuration--------------------------------------------------------*/

  /* Reset of all peripherals, Initializes the Flash interface and the Systick. */
  HAL_Init();

  /* Configure the system clock */
  SystemClock_Config();

  /* Initialize all configured peripherals */
  MX_GPIO_Init();
  MX_USART1_UART_Init();
  /* USER CODE BEGIN 2 */
  RetargetInit(&huart1);
  TM1638_DeInit();
//  setDisplayToString("d20", 0, 0, FONT_DEFAULT);
//  setDisplayToString("12", 0, 3, FONT_DEFAULT);
  sprintf(dispLow, "d%d", 12);
  setDisplayToString(dispLow, 0, 0, FONT_DEFAULT);
//  setDisplayToDecNumber(12345, 0, 0, NUMBER_FONT);
//  TM1638_ConfigDisplay(7, TM1638DisplayStateON);



//  TM1638_Init();
//  TM1638_ConfigDisplay(5, TM1638DisplayStateON);
//  TM1638_SetSingleDigit(1, 0);
//  TM1638_SetSingleDigit(2, 2);
//  TM1638_SetSingleDigit(3, 3);
//  TM1638_SetSingleDigit(4, 4);
//  TM1638_SetSingleDigit(5, 5);
//  TM1638_SetSingleDigit(6, 6);
  lastDetectTick = HAL_GetTick();




  /* USER CODE END 2 */

  /* Infinite loop */
  /* USER CODE BEGIN WHILE */
  while (1)
  {
    /* USER CODE END WHILE */

    /* USER CODE BEGIN 3 */
//	  printf("test\n");
	currentTick = HAL_GetTick();


	if((currentTick-lastPress)>DEBOUNCE_TIME_MS){
		readSW();
		if(debounceCheck(currentSwStates[Roll], Roll)){
			if(!currentSwStates[Roll]){
			  	//ADD FUNCTIONAL CODE HERE
				if(rolling == false){
					sprintf(dispHigh, "---");
					setDisplayToString(dispHigh, 0, 3, FONT_DEFAULT);
#ifdef DEBUG_1
					printf("Rolling...\r\n");
#endif
					rolling = true;
				}
				lastPress = HAL_GetTick();
			  }
		}

		if(debounceCheck(currentSwStates[Dice], Dice)){
			if(!currentSwStates[Dice]){
			  	//ADD FUNCTIONAL CODE HERE
				currentDice = (currentDice + 1) % NDICES;
				sprintf(dispLow, "d%02d", dices[currentDice]);
				setDisplayToString(dispLow, 0, 0, FONT_DEFAULT);
#if defined(DEBUG_1) || defined(DEBUG_3)
				printf("Current dice: D%d\r\n", dices[currentDice]);
#endif
				lastPress = HAL_GetTick();
			}
		}

		if(debounceCheck(currentSwStates[Speed], Speed)){
			if(!currentSwStates[Speed]){
				//ADD FUNCTIONAL CODE HERE
#ifdef DEBUG_1
				printf("uart test\r\n");
#endif
				lastPress = HAL_GetTick();
			  }
		}

		if(debounceCheck(currentSwStates[Mode], Mode)){
			if(!currentSwStates[Mode]){
	//			  currentDice = (currentDice + 1) % NDICES;
				HAL_GPIO_TogglePin(SW_HV_GPIO_Port, SW_HV_Pin);
				lastPress = HAL_GetTick();
			  }
		}


	}





//	  if((currentTick-lastPress)>DEBOUNCE_TIME_MS){
//
//		  if(!HAL_GPIO_ReadPin(SW_DICE_GPIO_Port, SW_DICE_Pin)){
//			  if(debounceCheck(readState, diceCode))
////			  currentDice = (currentDice + 1) % NDICES;
//			  HAL_GPIO_TogglePin(SW_HV_GPIO_Port, SW_HV_Pin);
//			  lastPress = HAL_GetTick();
//		  }
//
//		  if(!HAL_GPIO_ReadPin(SW_ROLL_GPIO_Port, SW_ROLL_Pin)){
////			  rolling = true;
//			  lastPress = HAL_GetTick();
//		  }
  }

  /* USER CODE END 3 */
}

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


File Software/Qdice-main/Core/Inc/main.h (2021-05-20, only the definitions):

#define SW_HV_Pin GPIO_PIN_13
#define SW_HV_GPIO_Port GPIOC
#define SW_ROLL_Pin GPIO_PIN_12
#define SW_ROLL_GPIO_Port GPIOB
#define SW_MODE_Pin GPIO_PIN_13
#define SW_MODE_GPIO_Port GPIOB
#define SW_SPEED_Pin GPIO_PIN_14
#define SW_SPEED_GPIO_Port GPIOB
#define SW_DICE_Pin GPIO_PIN_15
#define SW_DICE_GPIO_Port GPIOB
#define INT_PULSE_Pin GPIO_PIN_8
#define INT_PULSE_GPIO_Port GPIOA
#define INT_PULSE_EXTI_IRQn EXTI4_15_IRQn
#define SW_CLK_Pin GPIO_PIN_7
#define SW_CLK_GPIO_Port GPIOB
#define DISP_CS_Pin GPIO_PIN_8
#define DISP_CS_GPIO_Port GPIOB
#define DISP_DATA_Pin GPIO_PIN_9
#define DISP_DATA_GPIO_Port GPIOB

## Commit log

2021-04-04 base design complete
    [GM-hv.SchDoc, Q-Dice.PcbDoc, Q-Dice.PrjPcb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]
2021-04-08 updated schematic and layout. added artwork
    [BoostConverter.SchDoc, GM-hv.SchDoc, Q-Dice.PcbDoc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]
2021-04-17 added artwork, layout almost complete
    [Acrylic_plate.step, BoostConverter.SchDoc, GM-hv.SchDoc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]
2021-04-18 minor changes, sent to fab
    [GM-hv.SchDoc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]
2021-05-03 Fixed some mistakes
    [GM-hv.SchDoc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]
2021-05-03 fixed problems and added features to software boilerplate
    [Qdice-main.ioc, TM1638_platform.c, TM1638_platform.h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]
2021-05-05 Feat/fix(Hardware): Exported top plate plots and fixed minor pcb format error
    [Acrylic_plate.step, Q-Dice_outline.DXF, Top_plate.DXF]
2021-05-05 feat(Hardware): Exported top plate pdf
2021-05-07 feat(debug): added printf funcionality via UART)
2021-05-20 added tests. misc firmware changes
    [D6Rolls_1 - Copy.ods, D6Rolls_1.ods, Detection_times.ods]
2023-10-15 Added assembly outputs
    [Bill of Materials-Q-Dice.xlsx, Pick Place for Q-Dice.csv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]

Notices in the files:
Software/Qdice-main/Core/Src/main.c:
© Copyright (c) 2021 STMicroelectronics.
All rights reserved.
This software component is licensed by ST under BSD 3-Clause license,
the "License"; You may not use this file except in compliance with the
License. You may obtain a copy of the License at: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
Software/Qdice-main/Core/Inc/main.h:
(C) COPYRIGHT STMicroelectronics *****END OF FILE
